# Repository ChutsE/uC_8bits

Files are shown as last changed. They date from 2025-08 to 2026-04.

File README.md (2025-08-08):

######################## uArquitecture #############################


########################## INSTRUCTIONS ##############################


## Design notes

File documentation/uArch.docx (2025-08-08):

IP Tile – Jesús Esparza

## Overview

This tile was designed by the student Jesús Esparza as part of a custom microcontroller (uC) implementation. The design represents a minimalist yet functional 8-bit microcontroller, tailored for didactic and experimental purposes. It features a reduced instruction set composed of 16 essential operations, enabling memory access, I/O handling, control flow, and arithmetic/logic execution.

The internal architecture is structured around a simplified two-state finite state machine (FSM), which transitions between:

- FETCH – retrieves the instruction from program memory and decodes.
- EXECUTE – performs the operation.

Instruction Set

The instruction format uses a 16-bit word, segmented into an opcode and three additional fields (registers or immediate values, depending on the operation). The complete instruction set is summarized below:

INSTRUCTION | DATA[15:0] | | | | DESCRIPTION
| OPCODE | BYTE 2 | BYTE 1 | BYTE 0
NOP | 0x0 | x | x | x | Does nothing. Typically used for delay or alignment.
LOAD | 0x1 | reg_dst | ram_addr_src | | Loads a value from memory (ram_addr_src) into reg_dst
STORE | 0x2 | reg_src | ram_addr_dst | | Stores the contents of reg_src into memory at ram_addr_dst.
JMP | 0x3 | pc_dst | | | Unconditionally jumps to program counter address pc_dst
BEQ | 0x4 | pc_dst | | | Jumps to pc_dst if the last comparison (CMP) was equal.
BC | 0x5 | pc_dst | | | Jumps to pc_dst if a carry-out occurred in the last add (ADD).
IN | 0x6 | reg_dst | data_in* | | In bootstrap mode data_in storages in reg_dst, if it is not bootstrap mode reads data from input port and stores it in reg_dst, and data_in don’t care (xx).
OUT | 0x7 | reg_src | x | out_port | Sends the contents of reg_src to an output port (PORT0 or PORT1).
ADD | 0x8 | reg_dst | reg_a | reg_b | Adds reg_a and reg_b; stores the result in reg_dst. Sets the carry flag.
SUB | 0x9 | reg_dst | reg_a | reg_b | Subtracts reg_b from reg_a; result is stored in reg_dst.
AND | 0xA | reg_dst | reg_a | reg_b | Performs bitwise AND on reg_a and reg_b; stores the result in reg_dst.
OR | 0xB | reg_dst | reg_a | reg_b | Performs bitwise OR on reg_a and reg_b; stores the result in reg_dst.
NOT | 0xC | reg_dst | reg_a | x | Bitwise NOT on reg_a; result is stored in reg_dst.
CMP | 0xD | x | reg_a | reg_b | Compares reg_a and reg_b; updates equality flag but stores no result.
SHR | 0xE | reg_dst | reg_a | reg_b | Right shifts reg_a by reg_b bits; result stored in reg_dst.
SHL | 0xF | reg_dst | reg_a | reg_b | Left shifts reg_a by reg_b bits; result stored in reg_dst.

Memory Mapping

The microcontroller implements a memory map to support dual-phase operation:

- Bootstrapping mode (addresses 0x000 to 0x1FF): This region is writable using the IN instruction and can be used to pre-load register values or instructions during the initialization phase.
- Execution mode (addresses 0x200 and above): This region is dedicated to program execution. The control unit fetches and decodes instructions from this area once the system exits bootstrap mode.

Microarchitecture

The microcontroller consists of the following main components:

- Program Counter (PC): Generates instruction addresses, supports jumps and branches.
- ALU (Arithmetic Logic Unit): Supports 8-bit operations including addition, subtraction, logic gates, shifts, and comparisons.
- SRAM (Registers Bank): Allows read/write access to 256x8-bit memory block using dedicated control signals (write_en, saddr, data_in/out).
- GPIO: Facilitates communication with the outside world via in_gpio and out_gpio.
- Control Unit (CU): A finite-state machine that orchestrates instruction sequencing and data routing.

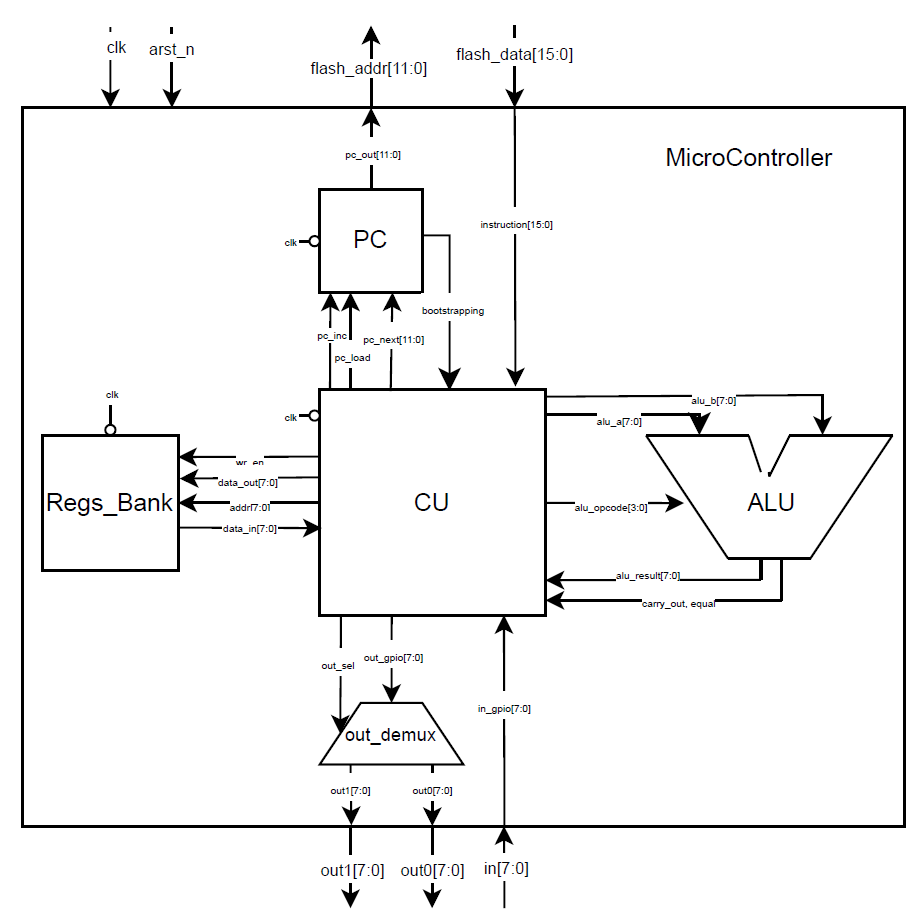
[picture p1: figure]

## Usage Guide

Folder Structure Requirement

Make sure you execute the script from inside the 'equipo_16' directory, where the following files are present:

- csr.py
- tests.py
- interface.py
- programs.py

Usage

Example command to run the default multiplication program:

python tests.py --test mul --cycles 1000 --inputs 9 5

Command-Line Arguments

Argument | Type | Default | Description
--test | str | "mul" | Name of the test program to execute. Must match a keyword defined in programs.py.
--cycles | int | 1000 | Number of cycles the test will run. Controls duration.
--verbose | flag | False | Enables detailed output for debugging.
--inputs | int list | [9, 4] | List of integer inputs for the test program.

Important Note

Before running any test, press the lower-right push button on the FPGA board to reset the system. This ensures proper synchronization over the UART interface.

Case 1

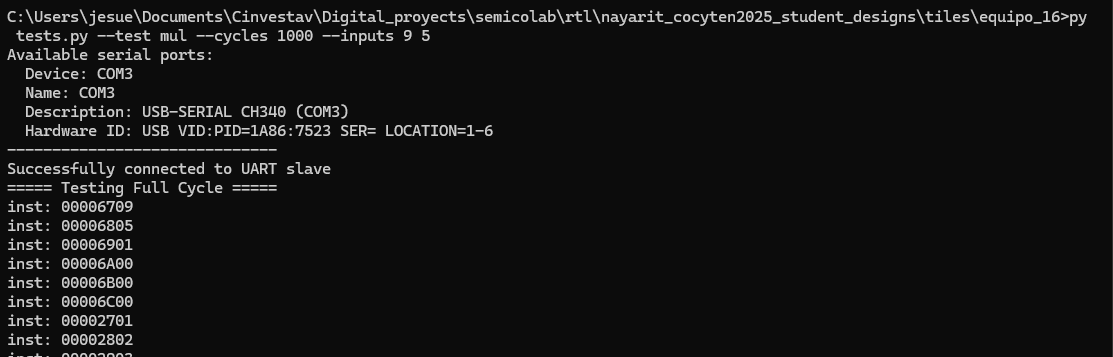
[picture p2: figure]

Inputs: 9, 5 → Result: 9 x 5 = 45 → Binary: 0b101101

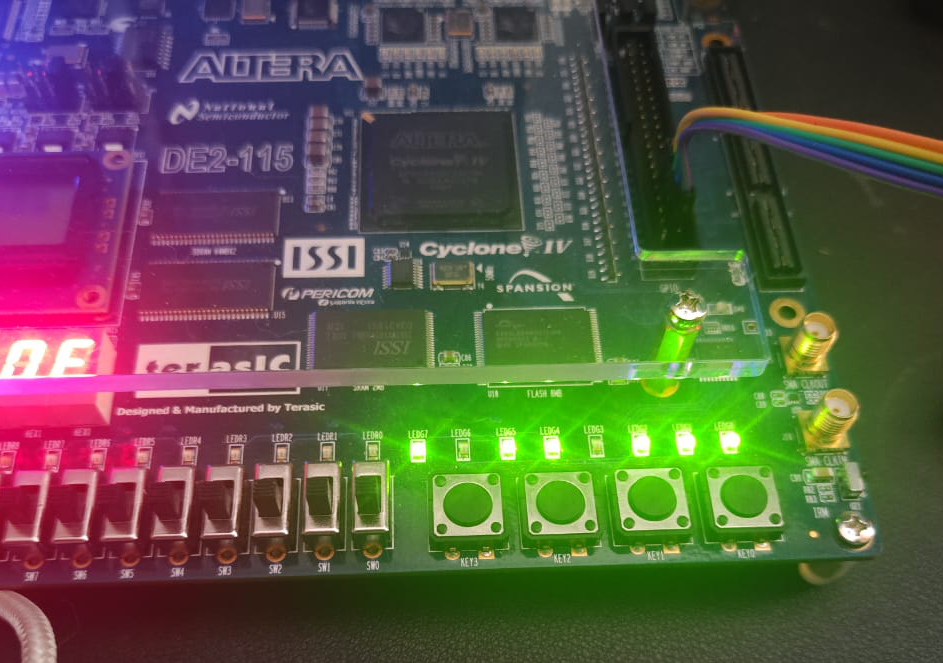
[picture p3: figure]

Case 2

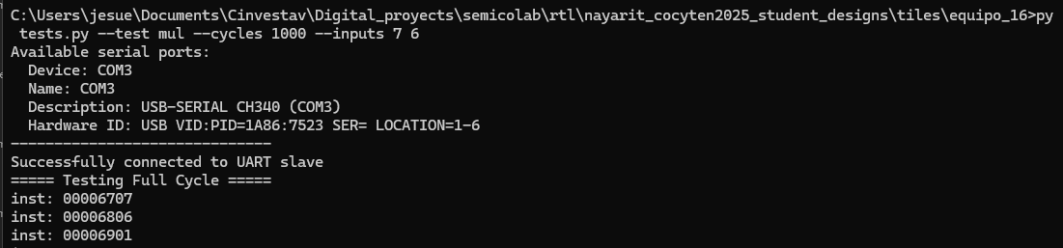
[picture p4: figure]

Inputs: 7, 6 → Result: 7 x 6 = 42 → Binary: 0b101010

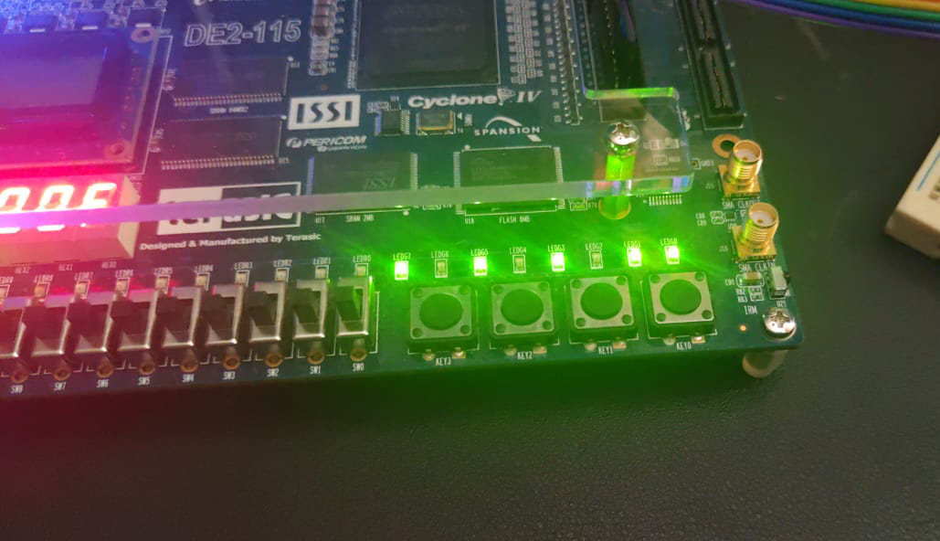
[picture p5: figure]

Custom Programs

By default, only the 'mul' program is defined in programs.py. To create and run additional tests:

- Add a new keyword in programs.py and define the instruction sequence.
- Run: python tests.py --test <your_keyword> --cycles 1000

Purpose of the "mul" Program

The 'mul' test program demonstrates how multiplication can be implemented using only 9 out of the 16 available instructions in the ISA: LOAD, STORE, IN, OUT, ADD, SUB, JMP, BEQ, and NOP. It showcases the uC’s capability to execute non-trivial logic using minimal instruction resources. The next picture show the program.

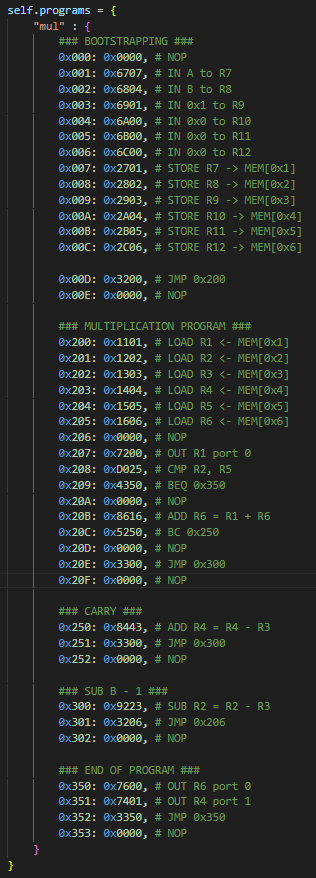
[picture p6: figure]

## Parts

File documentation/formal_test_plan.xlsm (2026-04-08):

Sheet: STATUS
BUS_SHIFT
ATTRIBUTE TYPE | NOT STARTED | IN PROGRESS | COMPLETED | PASSING | TOTAL
TESTCASE | 0 | 0 | 0 | 0 | 0
CHECK | 0 | 0 | 0 | 0 | 0
COVERGROUP | 0 | 0 | 0 | 0 | 0
GPIO_DEMUX
ATTRIBUTE TYPE | NOT STARTED | IN PROGRESS | COMPLETED | PASSING | TOTAL
TESTCASE | 0 | 0 | 0 | 0 | 0
CHECK | 0 | 0 | 0 | 0 | 0
COVERGROUP | 0 | 0 | 0 | 0 | 0
ALU
ATTRIBUTE TYPE | NOT STARTED | IN PROGRESS | COMPLETED | PASSING | TOTAL
TESTCASE | 0 | 0 | 0 | 0 | 0
CHECK | 0 | 0 | 0 | 0 | 0
COVERGROUP | 0 | 0 | 0 | 0 | 0
SRAM_64x8
ATTRIBUTE TYPE | NOT STARTED | IN PROGRESS | COMPLETED | PASSING | TOTAL
TESTCASE | 0 | 0 | 0 | 0 | 0
CHECK | 0 | 0 | 0 | 0 | 0
COVERGROUP | 0 | 0 | 0 | 0 | 0
PROGRAM_COUNTER
ATTRIBUTE TYPE | NOT STARTED | IN PROGRESS | COMPLETED | PASSING | TOTAL
TESTCASE | 0 | 0 | 0 | 0 | 0
CHECK | 0 | 0 | 0 | 0 | 0
COVERGROUP | 0 | 0 | 0 | 0 | 0
CONTROL_UNIT
ATTRIBUTE TYPE | NOT STARTED | IN PROGRESS | COMPLETED | PASSING | TOTAL
TESTCASE | 0 | 0 | 0 | 0 | 0
CHECK | 0 | 0 | 0 | 0 | 0
COVERGROUP | 0 | 0 | 0 | 0 | 0
UC_8BITS
ATTRIBUTE TYPE | NOT STARTED | IN PROGRESS | COMPLETED | PASSING | TOTAL
TESTCASE | 0 | 0 | 0 | 0 | 0
CHECK | 0 | 0 | 0 | 0 | 0
COVERGROUP | 0 | 0 | 0 | 0 | 0

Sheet: BUS_SHIFT
ID | Attribute | Attribute Type | Owner | Status | Description | fv file | Comments
BSR001 | bus_shift_x_propagation | REUSE | Jesus | PASSING | The in must not be unknown | fv_bus_shift.sv
BSR002 | bus_shift_data_shift | REUSE | Jesus | PASSING | the in must to be the same of out on the next time . | fv_bus_shift.sv

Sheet: SRAM_64x8
ID | Attribute | Attribute Type | Owner | Status | Description | fv file | Comments
SM001 | sram_clk_valid | REUSE | Jesus | PASSING | clk_valid must to be 1'b1 always | fv_sram_64x8.sv
SA001 | sram_read_memory | AST | Jesus | COMPLETED | sram_write_en low, sram_data_in must to be the same to memory[sram_addr] on the next time | fv_sram_64x8.sv
SA002 | sram_write_memory | AST | Jesus | PASSING | sram_write_en high, memory[sram_addr] must to be the same to sram_data_out on the next time | fv_sram_64x8.sv

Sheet: PROGRAM_COUNTER
ID | Attribute | Attribute Type | Owner | Status | Description | fv file | Comments
PCA001 | program_counter_clk_valid | REUSE | Jesus | PASSING | clk_valid must to be 1'b1 always | datapath/fv_program_counter.sv
PCA001 | program_counter_bootstrapping_hi | AST | Jesus | PASSING | when pc_out is under than BOOTSTRAP_THRESHOLD the bootstrapping must to be high | datapath/fv_program_counter.sv
PCA002 | program_counter_bootstrapping_low | AST | Jesus | PASSING | when pc_out is upper than BOOTSTRAP_THRESHOLD the bootstrapping must to be low | datapath/fv_program_counter.sv
PCR001 | program_counter_inc | AST | Jesus | COMPLETED | when pc_inc is high and pc_load is low the pc_out must to be increase plus one on the next time. | datapath/fv_program_counter.sv
PCR001 | program_counter_load | AST | Jesus | PASSING | when pc_load is high and pc_inc is low the pc_out must to be equal to pc_next on next time. | datapath/fv_program_counter.sv
PCR003 | program_counter_load_inc | REUSE | Jesus | PASSING | pc_inc and pc_load must not to be equal | datapath/fv_program_counter.sv
PCC001 | program_counter_limit | COV | Jesus | PASSING | cover when pc_out is PROGRAM_COUNTER_LIMIT and the pc_out must to be zero on next time. | datapath/fv_program_counter.sv

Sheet: CONTROL_UNIT
ID | Attribute | Attribute Type | Owner | Status | Description | fv file | Comments
CUR001 | control_unit_clk_valid | REUSE | Jesus | PASSING | clk_valid must to be 1'b1 always | fv_control_unit.sv
CUA001 | control_unit_nop | AST | Jesus | PASSING | when instr_opcode is equal to NOP and state is equal to STATE_FETCH, all output signals must to keep the values. | fv_control_unit.sv
CUA002 | control_unit_jmp | AST | Jesus | PASSING | when instr_opcode is equal to JMP and state is equal to STATE_FETCH, pc_next must to be equal to {reg_dst, reg_2, reg_1} on the next time. | fv_control_unit.sv
CUA003 | control_unit_beq | AST | Jesus | PASSING | when instr_opcode is equal to BEQ, state is equal to STATE_FETCH and equal is high, pc_next must to be equal to {reg_dst, reg_2, reg_1} on the next time. | fv_control_unit.sv
CUA004 | control_unit_bc | AST | Jesus | PASSING | when instr_opcode is equal to BC, state is equal to STATE_FETCH and carry_out is high, pc_next must to be equal to {reg_dst, reg_2, reg_1} on the next time. | fv_control_unit.sv
CUA005 | control_unit_in_bootstrapping | AST | Jesus | PASSING | when instr_opcode is equal to IN, state is equal to STATE_FETCH and pc_next <= BOOTSTRAP_THRESHOLD , in_gpio must to be equal to registers[reg_dst] on the next time. | fv_control_unit.sv
CUA006 | control_unit_in | AST | Jesus | PASSING | when instr_opcode is equal to IN, state is equal to STATE_FETCH and pc_next > BOOTSTRAP_THRESHOLD , {reg_2, reg_1} must to be equal to registers[reg_dst] on the next time. | fv_control_unit.sv
CUA007 | control_unit_out_port0 | AST | Jesus | PASSING | when instr_opcode equal to OUT and state is equal to STATE_FETCH and reg_2 is equal to PORT0, registers[reg_dst] must to be equal to out_gpio and out_port equal to PORT0 on the next time. | fv_control_unit.sv
CUA008 | control_unit_out_port1 | AST | Jesus | PASSING | when instr_opcode equal to OUT, state is equal to STATE_FETCH and reg_2 is equal to PORT1, registers[reg_dst] must to be equal to out_gpio and out_port equal to PORT1 on the next time. | fv_control_unit.sv
CUA009 | control_unit_add | AST | Jesus | PASSING | when instr_opcode equal to ADD and state is equal to STATE_FETCH , registers[reg_1] + registers[reg_2] must to be equal to {carry_out, registers[reg_dst]}on the next time. | fv_control_unit.sv
CUA010 | control_unit_sub | AST | Jesus | PASSING | when instr_opcode equal to SUB and state is equal to STATE_FETCH, registers[reg_1] - registers[reg_2] must to be equal to registers[reg_dst] on the next time. | fv_control_unit.sv
CUA011 | control_unit_and | AST | Jesus | PASSING | when instr_opcode equal to AND and state is equal to STATE_FETCH , registers[reg_1] & registers[reg_2] must to be equal to registers[reg_dst] on the next time. | fv_control_unit.sv
CUA012 | control_unit_or | AST | Jesus | PASSING | when instr_opcode equal to OR and state is equal to STATE_FETCH , registers[reg_1] | registers[reg_2] must to be equal to registers[reg_dst] on the next time. | fv_control_unit.sv
CUA013 | control_unit_not | AST | Jesus | PASSING | when instr_opcode equal to NOT and state is equal to STATE_FETCH , ~registers[reg_1] must to be equal to registers[reg_dst] on the next time. | fv_control_unit.sv
CUA014 | control_unit_cmp | AST | Jesus | PASSING | when instr_opcode equal to CMP and state is equal to STATE_FETCH , if registers[reg_1] is equal to registers[reg_2], equal signal will rise on the next time. | fv_control_unit.sv
CUA015 | control_unit_rsht | AST | Jesus | PASSING | when instr_opcode equal to RSHT and state is equal to STATE_FETCH, registers[reg_1] >> reg_2 must to be equal to registers[reg_dst] on the next time. | fv_control_unit.sv
CUA016 | control_unit_lsht | AST | Jesus | PASSING | when instr_opcode equal to LSHT and state is equal to STATE_FETCH , registers[reg_1] << reg_2 must to be equal to registers[reg_dst] on the next time. | fv_control_unit.sv

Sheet: UC_8BITS
ID | Attribute | Attribute Type | Owner | Status | Description | fv file | Comments
UR001 | uc_clk_valid | REUSE | Jesus | PASSING | clk_valid must to be 1'b1 always | fv_uc_8bits.sv
UA001 | uc_load | AST | Jesus | PASSING | when instr_opcode is equal to LOAD and state is equal to STATE_FETCH, memory[{reg_1, reg_2}] must to be equal to registers[reg_dst] on the next time. | fv_uc_8bits.sv
UA002 | uc_store | AST | Jesus | PASSING | when instr_opcode is equal to STORE and state is equal to STATE_FETCH, registers[reg_dst] must to be equal to memory[{reg_1, reg_2}] on the next time. | fv_uc_8bits.sv

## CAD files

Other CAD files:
Schematic.dwg

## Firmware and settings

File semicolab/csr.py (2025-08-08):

import serial
from serial.tools import list_ports
import numpy as np
import struct

class Csr:
    def __init__(self, port_name=None, baudrate=115200):
        self.port_name = port_name
        self.baudrate = baudrate
        self.serial = None

    def establish_connection(self):
        if not self.port_name:
            ports = list_ports.comports()
            if ports:
                print("Available serial ports:")
                for port in ports:
                    print(f"  Device: {port.device}")
                    print(f"  Name: {port.name}")
                    print(f"  Description: {port.description}")
                    print(f"  Hardware ID: {port.hwid}")
                    print("-" * 30)
                    try:
                        self.port_name = str(port.name)
                        self.serial = serial.Serial(self.port_name, baudrate=self.baudrate, timeout=1)
                        print("Successfully connected to UART slave")
                        break
                    except Exception as e:
                        print(f"Could not connect to uart slave: {e}")
                        continue
            else:
                print("No serial ports found.")
        else:
            try:
                self.serial = serial.Serial(self.port_name, baudrate=self.baudrate, timeout=1)
            except Exception as e:
                print(f"Could not connect to uart slave: {e}")

    def ser_wr_rd(self, data):
        self.serial.write(data)
        val = self.serial.read(np.size(data))

    def write_csr(self, addr, data):
        COMMAND = 1
        v = struct.pack('B', COMMAND)
        self.ser_wr_rd(v)
        v = struct.pack('B', addr) # B - 1 Byte, H - 2 Bytes, I - 4 Bytes, Q - 8 Bytes
        self.ser_wr_rd(v)
        v = struct.pack('I', data)
        self.ser_wr_rd(v)
        self.serial.reset_input_buffer()

    def read_csr(self, addr):
        COMMAND = 0
        v = struct.pack('B', COMMAND)
        self.ser_wr_rd(v)
        v = struct.pack('B', addr) # B - 1 Byte, H - 2 Bytes, I - 4 Bytes, Q - 8 Bytes
        self.ser_wr_rd(v)
        v = struct.pack('I', 0)
        self.serial.write(v)
        while self.serial.in_waiting < 4: pass
        val = self.serial.read(4)
        data_received = int.from_bytes(val, "little")
        return(data_received)

    def read_client_name(self):
        COMMAND = 0
        string_received = ""
        for i in range(8,3,-1):
            v = struct.pack('B', COMMAND)
            self.ser_wr_rd(v)
            v = struct.pack('B', i) # B - 1 Byte, H - 2 Bytes, I - 4 Bytes, Q - 8 Bytes
            self.ser_wr_rd(v)
            v = struct.pack('I', 0)
            self.serial.write(v)
            while self.serial.in_waiting < 4: pass
            val = self.serial.read(4)
            string_received = string_received + val[::-1].decode('utf-8')

    def read_owner_name(self):
        COMMAND = 0
        string_received = ""
        for i in range(13,8,-1):
            v = struct.pack('B', COMMAND)
            self.ser_wr_rd(v)
            v = struct.pack('B', i) # B - 1 Byte, H - 2 Bytes, I - 4 Bytes, Q - 8 Bytes
            self.ser_wr_rd(v)
            v = struct.pack('I', 0)
            self.serial.write(v)
            while self.serial.in_waiting < 4: pass
            val = self.serial.read(4)
            string_received = string_received + val[::-1].decode('utf-8')
        return(string_received)

    def transfer(self, bt):
        v = struct.pack('B', bt)
        self.serial.write(v)

    def close(self):
        if self.serial and self.serial.is_open:
            self.serial.close()

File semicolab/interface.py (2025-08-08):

from csr import Csr

class Interface(Csr):
    def __init__(self):
        super().__init__()
        self.tile_num = 0x0F
        self.data_reg_c = 0
        self.csr_in = 0
        self.program_counter = 0
        self.cu_state = 0
        self.data_reg_a = 0
        
    def refresh(self, verbose=True):
        self.data_reg_c = self.read_csr(3)
        self.program_counter = (self.data_reg_c) & 0xFFF
        self.cu_state = (self.data_reg_c >> 12) & 0x01
        if verbose:
            print("Program Counter: " + "{:08X}".format(self.program_counter))
            print("CU State: " + "{:08X}".format(self.cu_state))

    def load_instruction(self, instruction, verbose=True):
        self.data_reg_a = instruction & 0xFFFF
        if verbose:
            print("inst: " + "{:08X}".format(self.data_reg_a))

    def load_clock(self, clock, verbose=True):
        self.csr_in = (self.csr_in & ~(1 << 15)) | ((clock & 0x1) << 15)
        if verbose:
            print("Setting clock: " + "{:08X}".format(self.csr_in))

    def flush(self, verbose=True):
        self.write_csr(1, self.data_reg_a)
        self.write_csr(0, self.csr_in)
        if verbose:
            print("Flushing all CSR data")
        self.refresh(verbose=verbose)
    
    def enable_tile(self, tile = 0x0F):
        self.write_csr(14,0x00000000) # Clear client & owner enable
        self.write_csr(0,0xC2F29023) # Enable harness
        self.read_client_name() # Read and print client name
        self.write_csr(0,self.tile_num) # Enable tile
        self.read_owner_name() # Read Tile owner name
        self.read_owner_name() # Save owner name to owner variable

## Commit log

2025-08-03 adding instructions
    [instructions.xlsx]
2025-08-06 adding clk in crs
    [instructions.xlsx]
2026-01-23 several files moved to correct folder
    [instructions.xlsx]
2026-03-31 Schematic and programs added
    [Schematic.dwg]
2026-03-31 fv testplan added, schematics added
    [formal_test_plan.xlsm]
2026-03-31 schematics update
2026-04-01 prperties defineded for bus_shift and program_counter
    [formal_test_plan.xlsm]
2026-04-01 program counter plant updated
    [formal_test_plan.xlsm]
2026-04-03 control unit test plane defined
    [formal_test_plan.xlsm]
2026-04-08 uc test plan defined
    [formal_test_plan.xlsm]
2026-04-08 minor changes
    [formal_test_plan.xlsm]
